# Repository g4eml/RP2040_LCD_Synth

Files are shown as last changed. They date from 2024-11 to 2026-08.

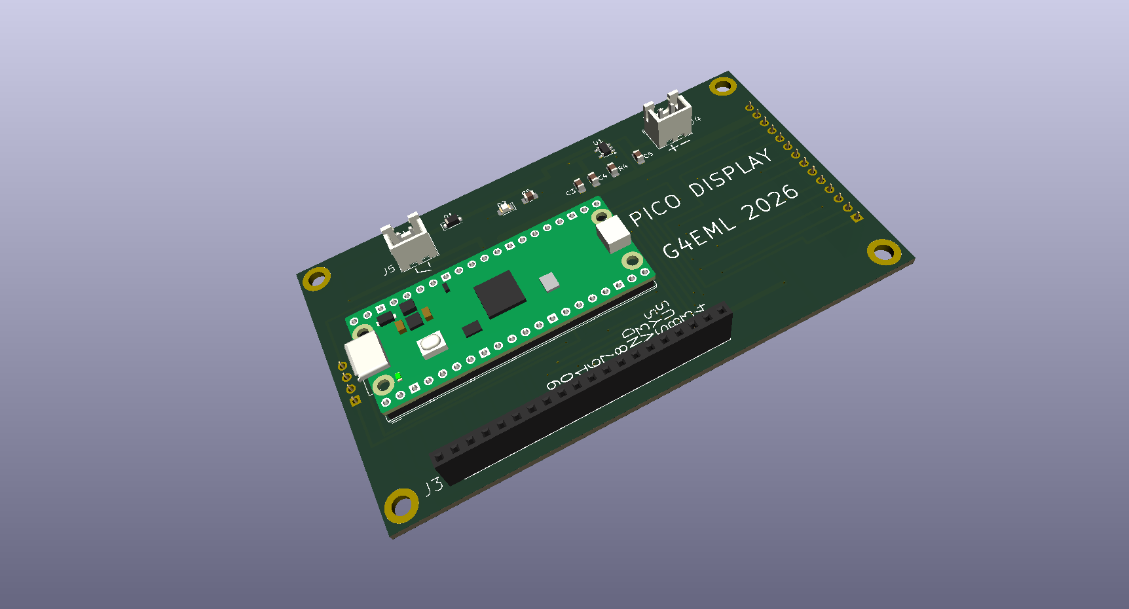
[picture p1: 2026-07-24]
PCB/Pico_Display_Image.png

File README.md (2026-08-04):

# RP2040_LCD_Synth

## Description

This Project is a development of the RP2040_Synth project with the addition of a Touch screen LCD display module, refered to here as the HMI Module (Human Machine Interface). This is intended to be used as a piece of test equipment. 
Currently supports 4 different type of synthesiser chip, the ADF4351, the Max2870, the LMX2595 and the ADF5355.

## Features

Control and configuration can be done from the Touch Screen or from a USB serial port connection. 

No special programming hardware or software required. 

Serial programming using the RP2040s built in USB serial port and standard boot loader. 

Settings are saved to EEPROM for automatic load on power on.

Support for FSK CW Identification for beacon use.

Supports data modes for Beacon Identification.  JT4G is available on all chip types. Q65 is only available on the LMX2595 and ADF5355.

Note:- Whilst JT4G mode is available on all chips there may be some limitations. The ADF4351 and MAX2870 chips have a limited frequency resolution and may not be able to accurately set the required tone frequencies especially when an external multiplication chain is used.

Supports GPS connection for the accurate timing required for data modes. 

Supports 10 different channels which can also be selected by external switches. 

Supports External Key Input with independently configurable FSK Shift. 

Default register settings can be loaded for all synthesiser types to produce some initial RF output. This is often the hardest thing to do with a new chip type.

Supports use with an external frequency multiplier for the higher microwave bands. Allows frequency entry and display of the final output frequency. Adjusts FSK shifts to compensate for multiplication factor.  

Direct output frequency and phase detector frequency entry. Register values are calculated automatically.  

## Requirements

This code was designed to work with the Elecrow CrowPanel Pico-3.5 inch 480x320 TFT LCD HMI Module. https://www.aliexpress.com/item/1005007250778536.html 

LCD_Main

Note:- similar HMI Panels are available using the ESP32 processor chip. Make sure that you are purchasing the RP2040 version. 

## Alternative Display

The correct module now appears to be difficult to obtain. A new interface board has been designed to allow a Raspberry Pi Pico to be fitted to a more easily available 3.5" TFT touch panel. Full Details can be found in the PCB folder. 

Display

Pico_Display_Image

The LCD screen, controller chip and Touch Screen controller appear to be exactly the same as the original module.
 
If you are searching for these online the critical points are that it needs to be a 3.5" display  320 x 480 resolution with an ILI9488 controller and touch screen. 
There are lots of similar displays out there but the correct ones are usually Red and have 14 connections at one end of the board and 4 connections at the other. Be careful as these are also available without the touch screen. 
Full schematic and PCB designs are in the PCB folder. 

## Synthesisers

Suitable Synthesiser boards are available from Ebay, Amazon, Ali Express, SV1AFN etc. 

ADF4351  max2870

lmx2595 SV1AFN

If you wish to use the data modes you will also need a GPS module to provide the necessary accurate timing.  

GPS

## Connecting

All of the various synthesiser moduels use different connectors and pinouts.

The simplest solution is to make an adaptor cable that plugs into the GP connector of the HMI module and fit suitable plugs for the modules to the other end. Keep the wiring as short as possible. Probably no more than 100mm long. 

The power can be provided by the USB-C connector marked 'USB' on the end of the HMI module

## Programming or updating the HMI Module (quick method)

This can be done either before or after the Syntesiser has been connected, it makes no difference. Updating to a new firmware version is done the same way.   

1. Locate the latest compiled firmware file 'RP2040_LCD_Synth.uf2' which will be found here https://github.com/g4eml/RP2040_LCD_Synth/releases and save it to your desktop. 

2. Connect the HMI Module to your PC using the USB-C port on the side. 

3. Hold down the BOOT button on the back of the HMI module and briefly press the Reset button. The RP2040 should appear as a USB disk drive on your PC.

3. Copy the .uf2 file onto the USB drive. The RP2040 will recognise the file and immediately update its firmware and reboot.

## Building your own version of the firmware (longer method and not normally required)

The RP2040 is programmed using the Arduino IDE with the Earl F. Philhower, III  RP2040 core. 

#### Installing the Arduino IDE

1. Download and Install the Arduino IDE 2.3.0 from here https://www.arduino.cc/en/software

2. Open the Arduino IDE and go to File/Preferences.

3. in the dialog enter the following URL in the 'Additional Boards Manager URLs' field: https://github.com/earlephilhower/arduino-pico/releases/download/global/package_rp2040_index.json

4. Hit OK to close the Dialog.

5. Go to Tools->Board->Board Manager in the IDE.

6. Type “RP2040” in the search box.

7. Locate the entry for 'Raspberry Pi Pico/RP2040 by Earle F. Philhower, III' and click 'Install'

### Installing the required libraries

1. From the Arduino IDE select (Tools > Manage Libraries)
2. Search for 'JTEncode' Scroll down to find the Etherkit JTEncode library by Jason Milldrum.
3. Click Install
4. Now search for 'TFT_eSPI' and find the TFT graphics library by Bodmer.
5. Click Install

#### Downloading the Software.

1. Download the latest released source code .zip file from https://github.com/g4eml/RP2040_LCD_Synth/releases

2. Save it to a convenient location and then unzip it.

The TFT_eSPI Library is unusual in that it needs to be configured to the TFT display in use by modifying library files. The required modified versions of the files are located in the 'LCD-eSPI Settings' folder of this repository. Copy the files 'Setup_Elecraft_HMI.h' and 'User_Setup_Select.h' from the downloaded 'LCD-eSPI Settings' folder to your Arduino libraries directory. This will normaly be found at 'Documents/Arduino/libraries/TFT_eSPI'

#### Programming the RP2040

1. Open the Arduino IDE and click File/Open

2. Navigate to the File RP2404Synth/RP2040_LCD_Synth.ino (downloaded in the previous step) and click Open.

3. Select Tools and make the following settings.

   Board: "Raspberry Pi Pico"
   
   Debug Level: "None"

   Debug Port: "Disabled"

   C++ Exceptions: "Disabled"

   Flash Size: "2Mb (no FS)"

   CPU Speed: "133MHz"

   IP/Bluetooth Stack: "IPV4 Only"

   Optimise: "Small (-Os)(standard)"

   RTTI: "Disabled"

   Stack Protection: "Disabled"

   Upload Method: "Default (UF2)"

   USB Stack: "Pico SDK"  

5. Connect the HMI Module to the USB port, hold down the BOOT button and briefly press the reset Button. 

6. Click Sketch/Upload.

The Sketch should compile and upload automatically to the Pico. If the upload fails you may need to disconnect the module and then hold down the BOOT button while reconnecting. 

## Connections

The pinout of the various Synthesiser modules tends to vary so it is difficult to give exact wiring diagrams.
The LMX2595 takes a lot of current so is best supplied from the USB 5V line using its own 3V3 regulator. The other chips can be powered from the 3V3 output of the HMI module. Power arrangements may need additional attention to minimise phase noise. 
The HMI module does not have a connector for the USB 5V supply. You may need to add your own additional wire for this. 

The generic wiring instructions are as follows:-

| HMI Module | ADF4351 | MAX2870 | LMX2595 | ADF5355 |
| :---:  |  :---:  |  :---:  | :---: |  :---:  |
|5V | N/C | N/C | 5V | 5V |
|3V3 | 3V3 | 3V3 | N/C |  N/C |
|GND | GND | GND | GND |  GND |
|GPO3 | CE | CE | CE | CE |
|GPO4 | MUX | MUX |  MUXout |  MUX |
|GPO5 | LE | LE | CSB |  LE |
|GPO6 | CLK | CLK | SCK |  CLK  |
|GPO7 | DAT | DATA  | SDI |  DAT  |

The firmware also supports the optional connection of a GPS module. This is used to accurately set the time, which is needed for the data modes. It is not needed for Local Oscillator or a CW only beacon. Any GPS module with a 3V3 output can be used. It needs to output NMEA data at 9600 Baud. One of the low cost NEO6M modules was used for development. 

| HMI Module | GPS Module |
| :---:  | :---: |
|GP0 |Rx |
|GP1 |Tx |

4 switches can be used to select the operating channel. (These are optional. If they are not used the power-up channel can be selected using the menu.)
The 4 inputs have internal pull up resistors to 3.3V. All that is needed is 4 switches to connect the pins to ground. 
Inverted logic is used. A grounded pin is read as a Logic 1. A floating pin is read as a logic 0.
For example, all pins left open circuit is read as channel 0. 

An external Morse Key can be connected between GP27 and Ground. This can be configured for FSK keying using the K Menu Option. 

| HMI Module | Function |
| :---:  | :---: |
|GP19 |Bit 0  Channel 1|
|GP20 |Bit 1  Channel 2|
|GP21 |Bit 2  Channel 4|
|GP26 |Bit 3  Channel 8|
|GP27 |External Key|

## Firmware description

On first use the screen will show the Touch calibration screen. Follow the instructions and touch each of the four corners of the screen. 

By default on power up the firmware will immediately send the EEPROM saved register values to the sunthesiser chip.  If the CW ident feature is enabled the ident will begin. If the Data mode is enabled the Data sequence will begin. Note that this will initially not be correctly timed. Once the GPS aquires its satellites the timing will synchronise. 

## Main Screen

LCD_Main

The main screen allows entry of output frequency, power setting and output On/Off. 

To change a value just click on the black box and a pop-up alphabetic or numeric keypad will appear. 

10 separate channels (memories) can be selected. 

The power setting is the value sent to the Synthesiser chip, the available range of values will be chip dependent. See the relevant datasheets for more details. 

Entry to the configuration screen is by the Config button. 

The Save button will save the current settings to the selected Channel. 

## Configuring directly from the LCD Screen config page. 

LCD_CONFIG

Configuration should be straightforward. First select the Synthesiser type, then enter the Reference Oscillator Frequency and PFD.  CW Ident and /or JT Mode can be configured if required. 
When complete select Exit to return to the main screen. Then on the main screen select Save to save the new settings to EEPROM. 

## Using the USB serial port and a terminal program such as Putty or Terraterm. Pressing any key should result in the menu being displayed.

Screenshot (112)

### Commands
Commands are entered by a single key press. Text and numbers require a carriage return to enter. Pressing Question Mark will usually give more detailed help. 
Changes to registers and parameters will be applied immediatey so you should be able to observe the result of the change in real time. 

#### The first three Menu Items are common to all channels. 

T = Select Chip Type. Allows the Synthesiser chip type to be selected. Normally only needed the first time you configure the firmware. This will also clear all memories and reset them to the default settings. 

O = Set Reference Oscillator Frequency. Sets the Reference Oscillator Frequency. Enter the actual frequency of your reference including any frequency error. The firmware will attempt to adjust for this. 

N = Set Channel Number. Enter the channel number from 0 to 9. This channel will then be loaded and you can adjust the settings using the menu. This overrides the channel selected by any external switches. if you wish to use external switches to select a channel then you must change this setting to 255 before saving the EEPROM. A setting of 255 enables external channel selection. 

#### The following menu settings are applied to the currently selected channel. Each channel may have different settings. 

D = Restores the Default Register Values for chip. Sets default values to all registers. Tries to program a 10Mhz PFD and requests a frequency. After this your Synthesiser should start to output RF. 

P = Enter PFD Frequency. Set the required PFD frequency. The firmware will attempt to get as close as possible to the requested value but not all values can be achieved.

M = Set External Multiplier. If the Synthesiser is followed by a multiplier for higher frequencies this option allows you to specify the multiplcation factor. Final Multiplied Frequencies can then be entered and viewed. 

F = Enter Output Frequency. Set the required output frequency. The firmware will attempt to calculate the closest register values to achieve this. Changing the PFD may improve the result. 

C = Calculate and display frequency from current settings. The firmware will calculte the expected output frequency from the current register settings. Useful to check after youy make manual changes.

V = View / Enter Variables for Registers. Allows viewing or entry of parameters using the same names as defined in the chip datasheet. Press ? for a full list of the available parameter names. 

R = View / Enter Registers Directly in Hex. Allws direct entry of regiser values in Hexadecimal. Useful when transfering values calculated by another program. 

I = Configure CW Ident. Alows entry of CW Ident, CW Speed, Ident Period and FSK Shift.  A shift of -800Hz is a typical value. Ident period is only valid for a CW only configuration. If a JT mode is also enbled then the CW ident will be sent every odd minute. 

J = Configure data modes. Allows entry of a 13 character message for JT4G. This would normally be the Callsign and Maidenhead locator. For Q65 this must be the callsign and 4 character locator. The ident will be sent every Even minute. Accurate timing requires a GPS module to be connected.

K = Configure External Key. An External Morse key can be connected and used to frequency shift the signal. The FSK Shift can be entered and is seperate from the CWID shift. 

G = View GPS NMEA data. This is used to test the GPS connection. when selected it will echo all GPS data to the screen. Press any key to exit this mode. 

S = Save Registers to EEPROM. Saves the current Synthesiser settings to EEPROM. They will then be automatically loaded on the next power cycle. You must do this at least once. 

X = Exit Menu. Exits from the menu, re-initialises the Synthesiser and starts the CW Ident. 

##

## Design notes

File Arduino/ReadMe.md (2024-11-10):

# This Folder contains the Arduino Sketch

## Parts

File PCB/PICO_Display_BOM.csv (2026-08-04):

Id | Designator | Footprint | Quantity | Designation | Supplier and ref
1 | A1 | RaspberryPi_Pico_Common_THT | 1 | RaspberryPi_Pico
2 | C3 | C_0805_2012Metric_Pad1.18x1.45mm_HandSolder | 1 | 100nF
3 | C4, C5 | C_0805_2012Metric_Pad1.18x1.45mm_HandSolder | 2 | 22uF
4 | D1 | D_SOD-123F | 1 | D_Schottky
5 | D2 | LED_0805_2012Metric_Pad1.15x1.40mm_HandSolder | 1 | LED
6 | J1 | PinSocket_1x14_P2.54mm_Vertical | 1 | Conn_01x14_Socket
7 | J2 | PinSocket_1x04_P2.54mm_Vertical | 1 | Conn_01x04_Socket
8 | J3 | PinSocket_1x20_P2.54mm_Vertical | 1 | Conn_01x18_Socket
9 | J4, J5 | JST_XH_B2B-XH-A_1x02_P2.50mm_Vertical | 2 | Conn_01x02_Pin
10 | R4 | C_0805_2012Metric_Pad1.18x1.45mm_HandSolder | 1 | 2K
11 | R5 | C_0805_2012Metric_Pad1.18x1.45mm_HandSolder | 1 | 4K7
12 | U1 | TSOT-23-5 | 1 | LTC4054ES5-4.2

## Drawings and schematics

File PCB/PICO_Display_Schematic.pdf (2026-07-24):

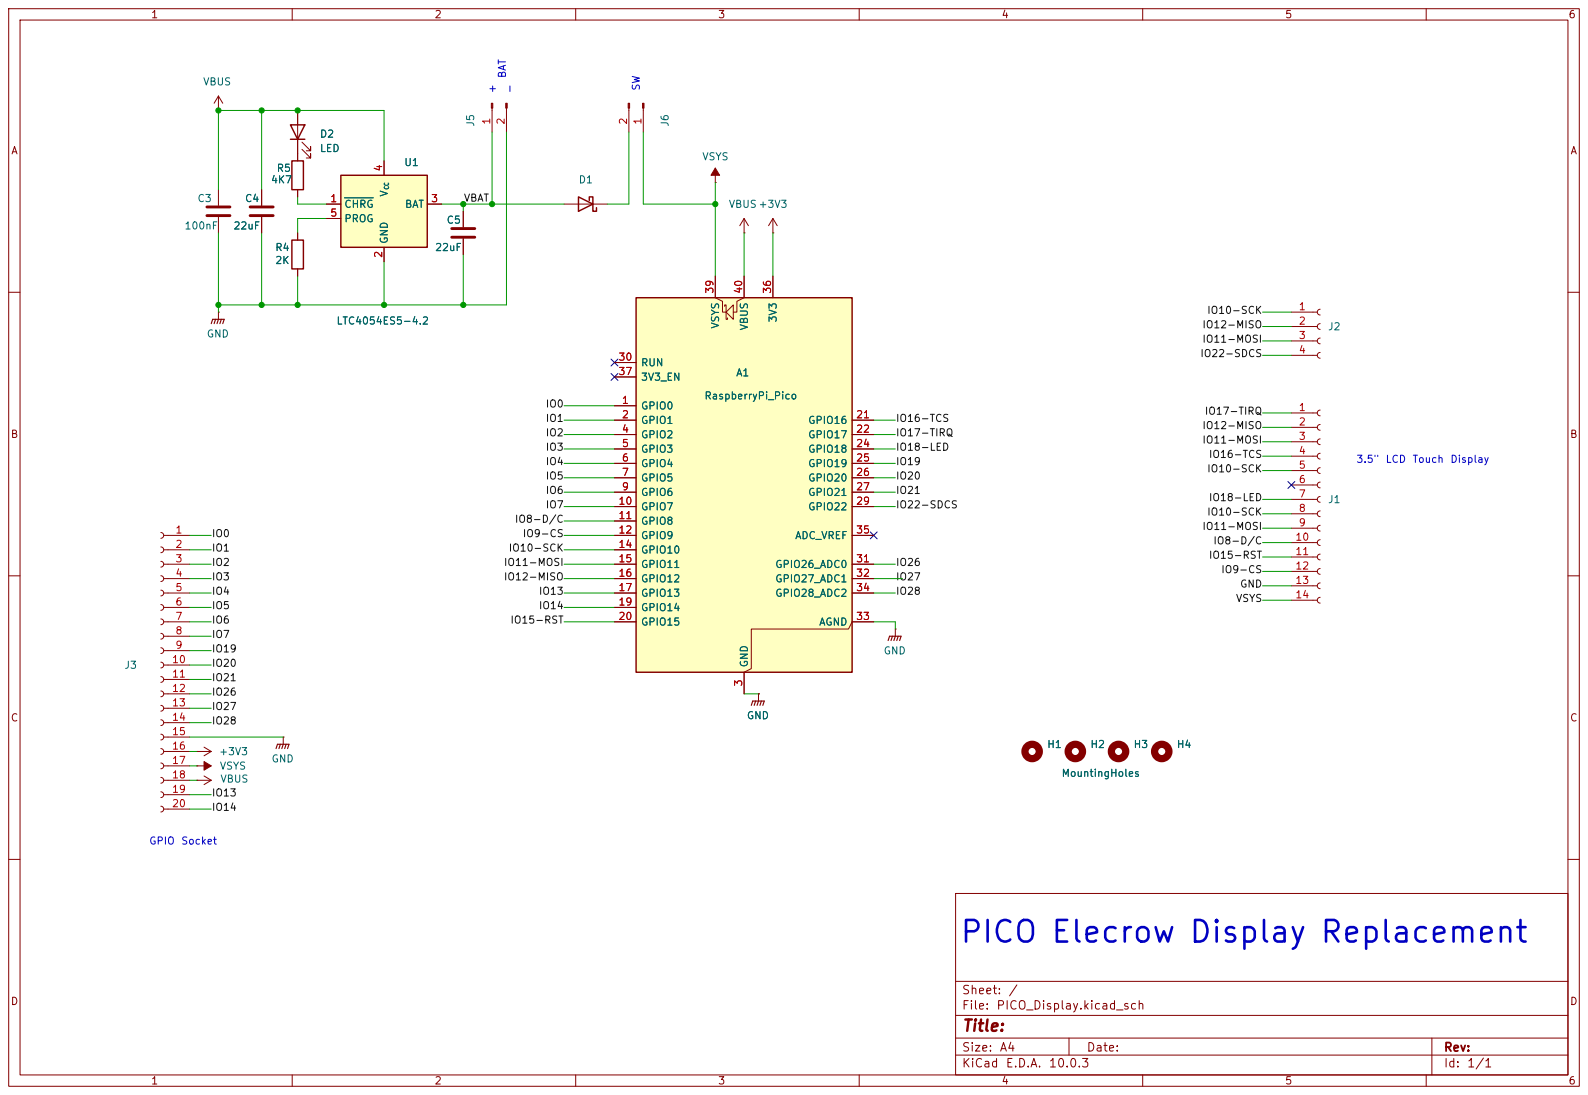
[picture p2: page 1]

PICO Elecrow Display Replacement

Size: A4 | Rev:
KiCad E.D.A. 10.0.3 | Id: 1/1

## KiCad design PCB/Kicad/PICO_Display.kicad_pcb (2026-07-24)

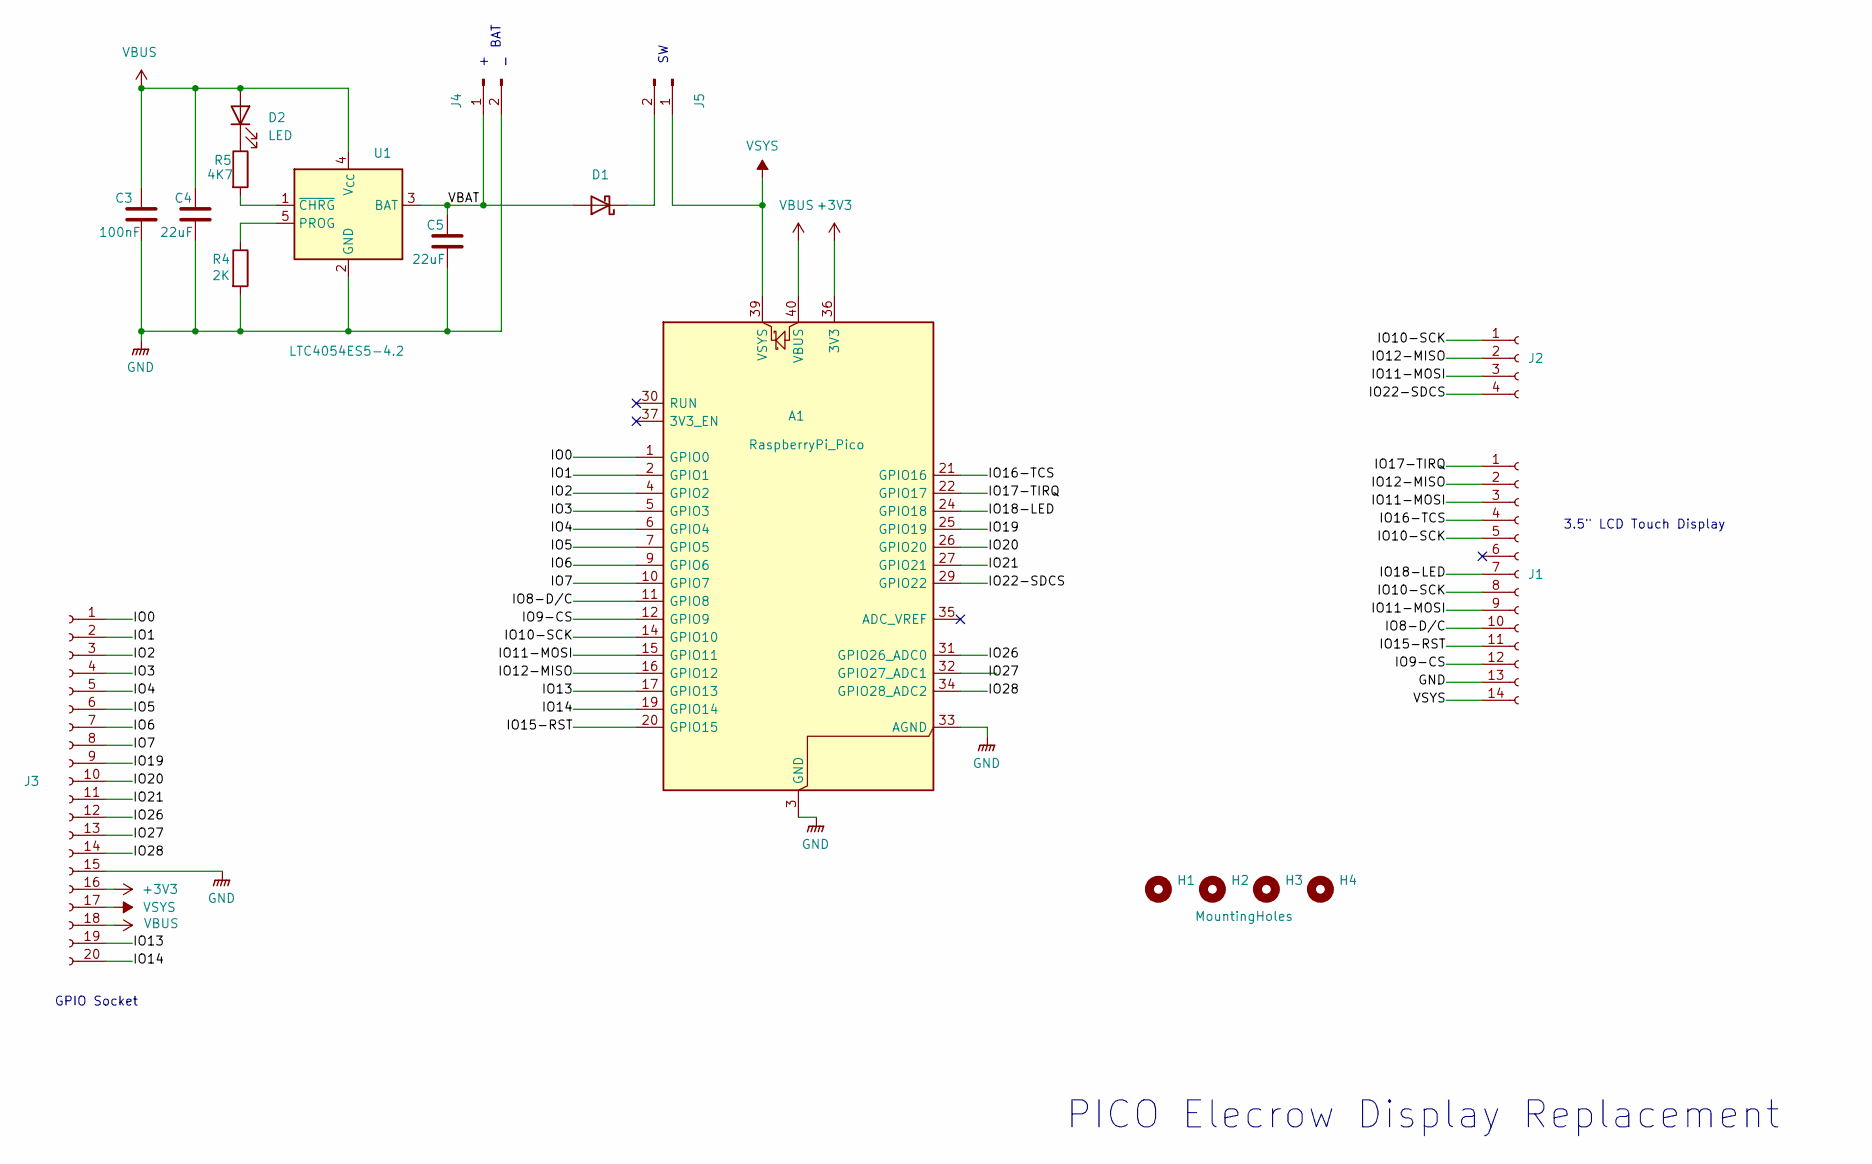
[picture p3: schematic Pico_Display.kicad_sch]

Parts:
A1: RaspberryPi_Pico; RaspberryPi_Pico_Common_THT
C3: 100nF; C_0805_2012Metric_Pad1.18x1.45mm_HandSolder
C4, C5: 22uF; C_0805_2012Metric_Pad1.18x1.45mm_HandSolder
D1: D_Schottky; D_SOD-123F
D2: LED; LED_0805_2012Metric_Pad1.15x1.40mm_HandSolder
H1, H2, H3: MountingHole; MountingHole_3.2mm_M3_ISO14580_Pad
H4: MountingHoles; MountingHole_3.2mm_M3_ISO14580_Pad
J1: Conn_01x14_Socket; PinSocket_1x14_P2.54mm_Vertical
J2: Conn_01x04_Socket; PinSocket_1x04_P2.54mm_Vertical
J3: Conn_01x18_Socket; PinSocket_1x20_P2.54mm_Vertical
J4, J5: Conn_01x02_Pin; JST_XH_B2B-XH-A_1x02_P2.50mm_Vertical
R4: 2K; C_0805_2012Metric_Pad1.18x1.45mm_HandSolder
R5: 4K7; C_0805_2012Metric_Pad1.18x1.45mm_HandSolder
U1: LTC4054ES5-4.2; TSOT-23-5

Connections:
+3V3: A1.36 (3V3), J3.16
/IO0: A1.1 (GPIO0), J3.1
/IO1: A1.2 (GPIO1), J3.2
/IO2: A1.4 (GPIO2), J3.3
/IO3: A1.5 (GPIO3), J3.4
/IO4: A1.6 (GPIO4), J3.5
/IO5: A1.7 (GPIO5), J3.6
/IO6: A1.9 (GPIO6), J3.7
/IO7: A1.10 (GPIO7), J3.8
/IO8-D/C: A1.11 (GPIO8), J1.10
/IO9-CS: A1.12 (GPIO9), J1.12
/IO10-SCK: A1.14 (GPIO10), J1.5, J1.8, J2.1
/IO11-MOSI: A1.15 (GPIO11), J1.3, J1.9, J2.3
/IO12-MISO: A1.16 (GPIO12), J1.2, J2.2
/IO13: A1.17 (GPIO13), J3.19
/IO14: A1.19 (GPIO14), J3.20
/IO15-RST: A1.20 (GPIO15), J1.11
/IO16-TCS: A1.21 (GPIO16), J1.4
/IO17-TIRQ: A1.22 (GPIO17), J1.1
/IO18-LED: A1.24 (GPIO18), J1.7
/IO19: A1.25 (GPIO19), J3.9
/IO20: A1.26 (GPIO20), J3.10
/IO21: A1.27 (GPIO21), J3.11
/IO22-SDCS: A1.29 (GPIO22), J2.4
/IO26: A1.31 (GPIO26_ADC0), J3.12
/IO27: A1.32 (GPIO27_ADC1), J3.13
/IO28: A1.34 (GPIO28_ADC2), J3.14
/VBAT: C5.2, D1.2 (A), J4.1, U1.3 (BAT)
GND: A1.3 (GND), A1.8 (GND), A1.13 (GND), A1.18 (GND), A1.23 (GND), A1.28 (GND), A1.33 (AGND), A1.38 (GND), C3.1, C4.1, C5.1, J1.13, J3.15, J4.2, R4.2, U1.2 (GND)
unnamed: D1.1 (K), J5.2
unnamed: D2.1 (K), R5.1
unnamed: R4.1, U1.5 (PROG)
unnamed: R5.2, U1.1 (~CHRG)
VBUS: A1.40 (VBUS), C3.2, C4.2, D2.2 (A), J3.18, U1.4 (V_{CC})
VSYS: A1.39 (VSYS), J1.14, J3.17, J5.1

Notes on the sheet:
PICO Elecrow Display Replacement
BAT
3.5" LCD Touch Display
GPIO Socket

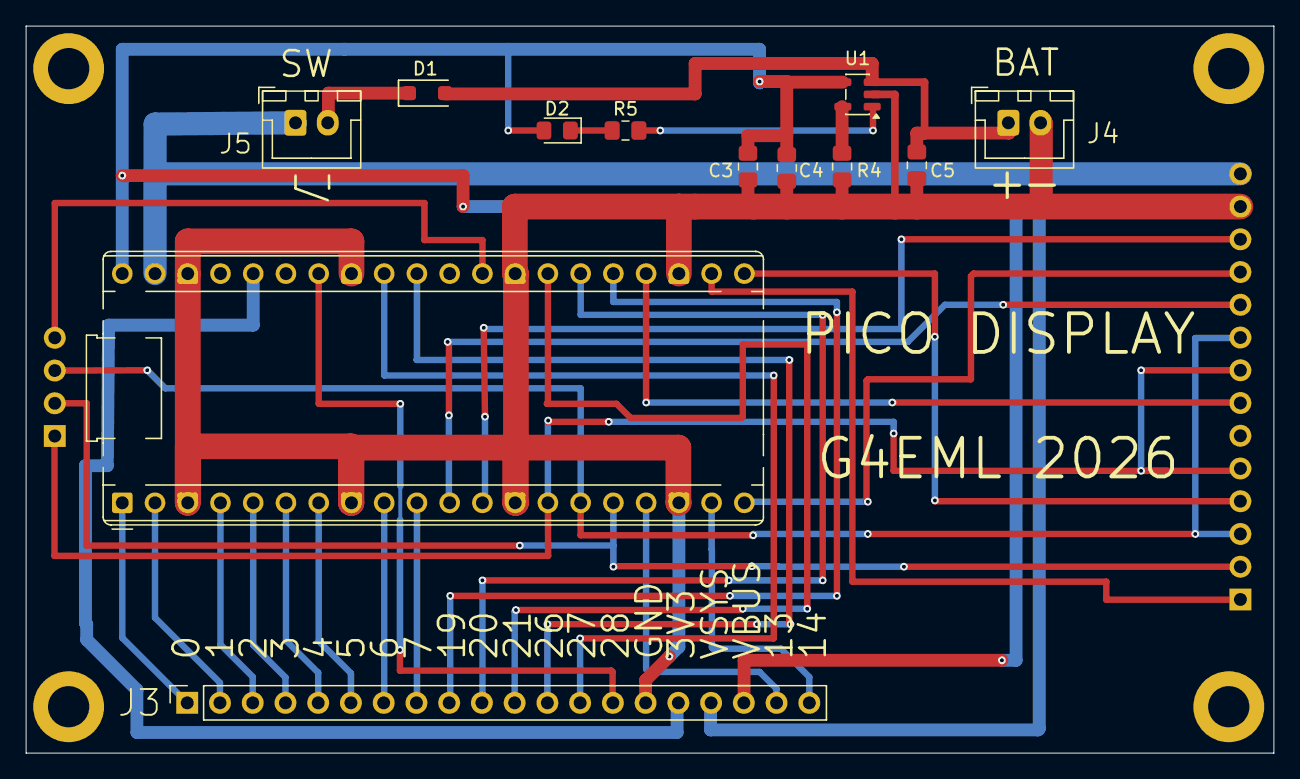
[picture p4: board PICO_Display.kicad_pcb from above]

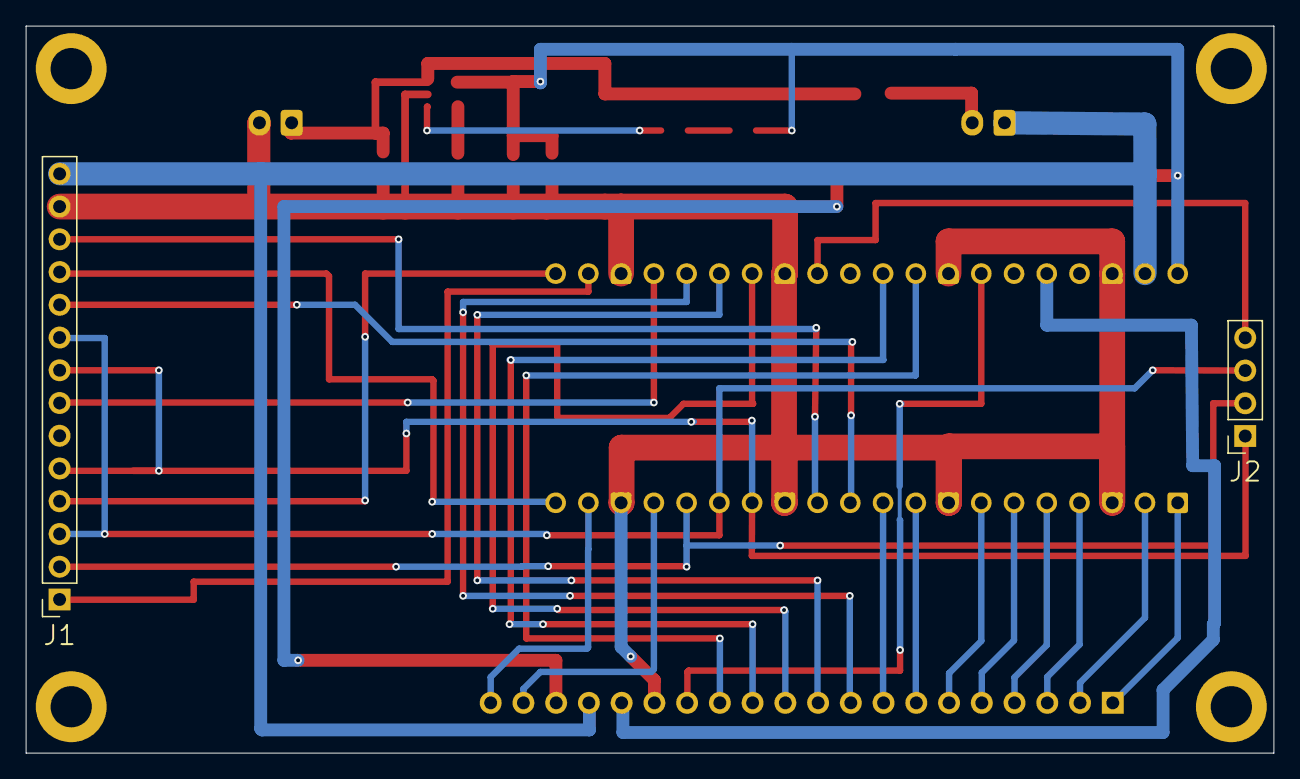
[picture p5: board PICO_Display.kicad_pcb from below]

Board: 2 copper layers, 96.8 x 56.4 mm, 18 parts (2 on the bottom side), 35 nets.

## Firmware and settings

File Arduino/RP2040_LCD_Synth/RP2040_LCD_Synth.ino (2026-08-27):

// Synthesiser controller with touchscreen LCD interface
// Colin Durbridge G4EML 2024
// Optional support for LCD controller using crowpanel 3.5" HMI panel.

#include "SynthChip.h"
#include "ChipList.h"

#define LCDVERSION

#define VERSION 2.00

#define EEPROMVER 0x53

#define NUMBEROFCHANNELS 10

//Global values...

//enum chipType and NUM_CHIP_TYPES are both generated from CHIP_LIST in ChipList.h -
//to add a new chip type, edit that list, not this one.
enum chipType
{
  NONE,
  #define CHIP_ENTRY(name, instance) name,
  CHIP_LIST
  #undef CHIP_ENTRY
  NUM_CHIP_TYPES        //always 1 past the last valid chip type; also equals the number of chip types including NONE
};

//Each chip's display name is set in its own constructor (see e.g. MAX2870.ino) and
//retrieved via chipTypeName(index) in redirects.ino - there is no separate name list to update.

//Pointer to the SynthChip object for the currently selected chip type.
//Set (and kept in sync with "chip") by chipInit() in redirects.ino.
//To add a new chip type see the notes at the top of SynthChip.h.
SynthChip* activeChip = nullptr;

bool saveRequired = false;

//These values are saved to the eeprom for recall on statup. 
//these values alpply to all channels

uint8_t chip = MAX2870;                 //index to the current chip type (applies to all channels)
uint8_t selChan = 0;                    //FF if channel is externally selected by switches. Channel number to force one channel. 
double refOsc = 100.000 ;               //reference oscillator frequency in MHz (applies to all channels)
uint16_t batcal = 492;                  //battery calibration value

//Bit definitions for fskMode flags

#define CWIDBIT 0x01
#define NOTCWIDBIT 0xFE
#define EXTKEYBIT 0x02
#define NOTEXTKEYBIT 0xFD

//this structure is repeated for each channel

struct chanstruct
{
uint32_t reg[80];                       // allow for up to 80 32 bit registers. 
uint8_t fskMode = 0;                    // 8 flag bits to indicate enabled special FSK modes.  Bit 0 = CWID   Bit 1 = External Key  
uint8_t cwidLen = 1;                    //number of characters in the CWID
uint8_t cwidSpeed = 10;                 //CWID speed in words per minute
uint8_t cwidInterval = 60;              //CWID Inteval in seconds.
float cwidShift = 0;                    //CW ID FSK Shift in MHz 
float keyShift = 0;                     //external key FSK Shift in MHz 
char cwid[32] = " ";                    // up to 30 CWID characters
uint8_t jtMode = 0;                     //JT mode
char jtid[13] = " ";                    //JT Message
float jtTone1 = 0;                      //JT Tone 1 Offset from Nominal Frequency (Mhz)
uint8_t jtInterval = 60;              //Digi mode Interval in seconds.
uint8_t extMult = 1;                    //Multiplcation factor for external frequency multiplier. (used to calculate the correct FSK Shifts.)
};

struct chanstruct chanData[NUMBEROFCHANNELS];


//End of saved values

//Note: numberOfRegs, maxPfd, minPfd, maxOsc, minOsc, jt4Only and jtDisable used to be
//duplicated here as globals, kept in sync with the selected chip by chipInit(). They are
//now read directly from activeChip (e.g. activeChip->numberOfRegs) wherever needed, so
//there is only one copy of this data - the one on the chip object itself.
uint8_t channel = 0;                      //currently active channel.

uint32_t cwidKeyUpN = 1;                  //key up value for the PLL N used to shift the frequency for CWID. Calculated by cwidInit()
uint32_t cwidKeyUpNum = 1;                //Key up value for the PLL numerator used to shift the frequency for CWID. Calculated by cwidInit()
uint32_t cwidKeyUpDen = 1;                //Key up value for the PLL denominator used to shift the frequency for CWID. Calculated by cwidInit()

uint32_t ExtKeyUpN = 1;                  //key up value for the PLL N used to shift the frequency for External Key. Calculated by ExtKeyInit()
uint32_t ExtKeyUpNum = 1;                //Key up value for the PLL numerator used to shift the frequency for External Key. Calculated by ExtKeyInit()
uint32_t ExtKeyUpDen = 1;                //Key up value for the PLL denominator used to shift the frequency for External Key. Calculated by ExtKeyInit()

void saveSettings(void);

#include <EEPROM.h>
#include <SPI.h>
#include <JTEncode.h>



#define JT4G_TONE_SPACING        315         // 72 * 4.37 Hz
#define JT4_DELAY                229         // Delay value for JT4
#define Q65_TONE_SPACING        3.33333       // 3.3333 Hz for Mode 30A
#define Q65_DELAY               150         // Delay in ms for Q65 15
#define Q65_SYMBOL_COUNT     85          //85 symbols


uint8_t jtBuffer[256];
uint8_t jtSymbolCount;
uint16_t jtToneDelay;
double jtToneSpacing;
uint8_t jtNumberOfTones;

uint32_t jtN[66];               //Note Element 0 is the nominal frequency. Element 1 is the Tone 1 frequency
uint32_t jtNum[66];
uint32_t jtDen[66];


JTEncode jtEncode;

int seconds = 0;                         //seconds counter.  counts up to 120 seconds.  0-60 is even minute. 60-120 is odd minute. 
int milliseconds = 0;                   //millisecond counter used to increment seconds counter. 

bool cwidActive = false;                //flag to start sending CW ID
int nextcwidTime = 60;                   //trigger time for next CWID

bool jtActive = false;                  //flag to start Jt Sending
int  nextjtTime = 1;                       //trigger time for next JT sequence

bool lastKeyState = 1;                 //external key state last pass 1 = key up 0 = key down

#define GPSTXPin 0                      //Serial data to GPS module 
#define GPSRXPin 1                      //SeriaL data from GPS module

//The touchscreen board's TFT_eSPI wiring uses GPIO 10-14, so channel select and
//external key use different pins here than on the non-LCD board.
#define CHANSEL0Pin 19                  //External channel select pins. Pulled up to 3V3. High is Logic 0 Low is Logic 1
#define CHANSEL1Pin 20
#define CHANSEL2Pin 21
#define CHANSEL3Pin 26
#define EXTKEYPin 27                    //External Key input Pulled upp to 3V3 ground to key

char gpsBuffer[256];                     //GPS data buffer
int gpsPointer;                          //GPS buffer pointer. 
char gpsCh;
int gpsSec = -1;                         //gps Seconds counter 0-59 is even minute, 60-119 is odd minute. -1 is GPS Invalid 
bool gpsActive = false; 
int lastsec=0;
int gpsH=0;
int gpsM=0;
int gpsS=0;

bool showSync=false;
bool showingGPS = false;
int gpstimeout =0;

#include <TFT_eSPI.h>      // Hardware-specific library. Must be pre-configured for this display and touchscreen
TFT_eSPI tft = TFT_eSPI(); // Invoke custom library
// Set REPEAT_CAL to true instead of false to run calibration again, otherwise it will only be done once.
#define REPEAT_CAL false
uint16_t t_x = 0, t_y = 0; // To store the touch coordinates

//Set true by a screen/pad right before it returns after acting on a touch (e.g.
//selecting an item from a popup list). While true, getTouchDebounced() reports
//"not touched" regardless of what the touch controller says, so the same
//physical touch can't immediately bleed through and re-trigger something on the
//screen underneath as soon as it redraws. Cleared automatically the first time
//a genuine release is seen. See getTouchDebounced() in commonScreen.ino.
bool touchConsumed = false;

void setup() 
{
  Serial.begin();                       //USB serial port
  analogReadResolution(12);
  Serial1.setRX(GPSRXPin);              //Configure the GPIO pins for the GPS module
  Serial1.setTX(GPSTXPin);

  pinMode(CHANSEL0Pin, INPUT_PULLUP);   //configure the channel select pins. 
  pinMode(CHANSEL1Pin, INPUT_PULLUP);   //Inverted logic to allow switches to ground. 
  pinMode(CHANSEL2Pin, INPUT_PULLUP);
  pinMode(CHANSEL3Pin, INPUT_PULLUP);

  pinMode(EXTKEYPin, INPUT_PULLUP);     //configure the external Key Input

  Serial1.begin(9600);                  //start GPS port comms on pins 0 and 1
  gpsPointer = 0;
  delay(1000);
  EEPROM.begin(4096);
  if(EEPROM.read(0) == EEPROMVER)        //magic number to indcate EEPROM is valid
    {
      EEPROM.get(1,chip);              //chip type for all channels
      EEPROM.get(2,selChan);           //read the selected channel. 0xFF if externally switched.
      EEPROM.get(3,refOsc);           //reference oscillator for all channels.
      EEPROM.get(11,batcal);          //battery cal factor 
      EEPROM.get(13,chanData);         //get channel data structure.
      if(selChan == 255)
        {
          channel = readChannelInputs();      //read the channel select bits. 
        }
      else
        {
          channel = selChan;          //fix the channel number. 
        } 
    }
  else
    {
      changeChip();                 //blank/invalid EEPROM - force reset of all channels to valid defaults.
    }
   chipInit();
   initChannel();
   seconds = -1;

  tft.init();
  tft.setRotation(1);
  if(homeScreenTouched())
   {
    while(homeScreenTouched());
    delay(1000);
    touch_calibrate(1);
   }
   else
   {
    touch_calibrate(0);
   }
  homeScreenUpdate();

}

void loop() 
{
  Serial.print("\n");
  Serial.print(chipTypeName(chip));
  Serial.println(" Synthesiser programmed, Sleeping");

  chipUpdate();
  delay(100);
  chipUpdate();
  
  unsigned long loopTimer = millis();
  while(1)
   {
     while(loopTimer == millis());          //hang waiting for the next 1mS timeslot
     loopTimer = millis();
     milliseconds++;
     if(milliseconds == 1000)
      {
        seconds++;
        milliseconds = 0;
        if(seconds == 120)
          {
            seconds = 0;
          }
        displayVolts();
      }

     if((gpsSec !=-1)&&(gpsS != lastsec))
       {
        lastsec=gpsS;
        displayGPS();
        showingGPS = true;
        gpstimeout = 0;
        if(gpsSec != seconds) 
         {
          seconds = gpsSec;
          milliseconds = 500;
         }      
       }

    if(showingGPS)
    {
      gpstimeout++;
    }

    if((gpstimeout > 10000) && (showingGPS))
      {
        showingGPS = false;
        gpsSec = -1;
        homeScreenUpdate();
      }

//synchronise the local clock to the GPS clock if available

     if(selChan == 255)             //external chaannel selection
       {
         uint8_t newChan=readChannelInputs();
         if(newChan != channel)
           {
            channel=newChan;
            seconds = -1;                       //reset the timing after changing channel.
            milliseconds = 0;
            jtActive = false;
            cwidActive = false;
            chipUpdate();
            initChannel();
           }

       }

     if((chanData[channel].fskMode & CWIDBIT) && (seconds == nextcwidTime))
       {
        cwidActive = true;                                        //start this CW ID
        nextcwidTime = (seconds + chanData[channel].cwidInterval) % 120;            //schedule the next CW ID
       }

     if((chanData[channel].jtMode != 0) && (seconds == nextjtTime))
       {
        jtActive = true;                                        //start the JT Sequence
        nextjtTime = (seconds + chanData[channel].jtInterval) % 120;            //schedule the next CW ID
       }

    if(chanData[channel].fskMode & CWIDBIT)
      {
        cwidTick();
      }

    if(chanData[channel].jtMode != 0)
      {
        jtTick();
      }

    if(chanData[channel].fskMode & EXTKEYBIT)
      {
        keyTick();
      }

      if(Serial.available() > 0 )          //test for USB command connected
     {
      bool valid = false;
         while(Serial.available())
         {
           if(Serial.read() == 13)
            {
              valid = true;
            }
         }
       if(!valid) return;
       chipExtKey(true);                    //reset to nominal carrier frequency
       mainMenu();                         //timing loop stops while the menu system is running.
       seconds = -1;                       //reset the timing after using the menu.
       milliseconds = 0;
       initChannel();  
       chipUpdate();    
       Serial.print("\nSynthesiser programmed. Press any key for menu");
       delay(500);
       flushInput();
     }
    
    if(Serial1.available() > 0)           //data received from GPS module on pins 0 and 1
      {
        while(Serial1.available() >0)
          {
            gpsCh=Serial1.read();
            if(gpsCh > 31) gpsBuffer[gpsPointer++] = gpsCh;
            if((gpsCh == 13) || (gpsPointer > 255))
              {
                gpsBuffer[gpsPointer] = 0;
                processNMEA();
                gpsPointer = 0;
              }
          }

      }

   if(homeScreenTouched())
    {
    if(processHomeScreenTouch())
      {
       homeScreenUpdate();
      }
    }   

  }  
}

void initChannel()
{
  chipDecodeRegs();
  if(chanData[channel].fskMode & CWIDBIT)
    {
      cwidInit();
    }
   
  if(chanData[channel].fskMode & EXTKEYBIT)
    {
      keyInit();
    }

   if(chanData[channel].jtMode)
     {
       jtInit();
     }


}

void processNMEA(void)
{
  float gpsTime;

 if(strstr(gpsBuffer , "RMC") != NULL)                         //is this the RMC sentence?
  {
    if(strstr(gpsBuffer , ",A,") != NULL)                       // is the data valid?
      {
       int p=strcspn(gpsBuffer , ",");                         // find the first comma
       gpsTime = strtof(gpsBuffer+p+1 , NULL);                 //copy the time to a floating point number
       gpsSec = 60 * ((int(gpsTime) / 100) % 2);                 // count odd and even minutes
       gpsSec = gpsSec + (int(gpsTime) % 100); 
       gpsH=int(gpsTime)/10000;
       gpsM=(int(gpsTime)/100) % 100;
       gpsS= int(gpsTime) % 100;
       gpsActive = true;
      }
    else
     {
       gpsSec = -1;                                            //GPS time not valid
     }
  }


}

uint8_t readChannelInputs(void)
{
  uint8_t ch;
  ch = (digitalRead(CHANSEL3Pin) << 3) | (digitalRead(CHANSEL2Pin) << 2) | (digitalRead(CHANSEL1Pin) << 1) | (digitalRead(CHANSEL0Pin));
  ch = ~ch & 0x0F;           //invert the logic and limit to 4 bits. 
  if(ch > (NUMBEROFCHANNELS -1)) ch = NUMBEROFCHANNELS-1;
  return ch;
}

void saveSettings(void)
{
    EEPROM.write(0, EEPROMVER);         //magic number to indcate EEPROM is valid
    EEPROM.put(1,chip);            //save the chip type
    EEPROM.put(2,selChan);         //Save the currently selected channel
    EEPROM.put(3,refOsc);          //reference oscillator for all channels.
    EEPROM.put(11,batcal);           //battery calibration factor
    EEPROM.put(13,chanData);         //get channel data structure. 
    EEPROM.commit();
}

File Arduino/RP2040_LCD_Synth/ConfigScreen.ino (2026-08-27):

//Chip type - single field showing the current chip; tap to open the full
//auto-populated selection list (see ChipPad.ino). No positions to add here
//when a new chip type is added.
#define CHIP_LX 10
#define CHIP_LY 15
#define CHIP_X 130
#define CHIP_Y 5
#define CHIP_W 200
#define CHIP_H 20

//Reference Frequency
#define REF_LX 10
#define REF_LY 40
#define REF_X 180
#define REF_Y 30
#define REF_W 110
#define REF_H 20

//PFD
#define PFD_LX 320
#define PFD_LY 40
#define PFD_X 370
#define PFD_Y 30
#define PFD_W 105
#define PFD_H 20

//MULT
#define MULT_LX 10
#define MULT_LY 65
#define MULT_X 180
#define MULT_Y 55
#define MULT_W 40
#define MULT_H 20

//Key Shift
#define KEYSH_LX 10
#define KEYSH_LY 90
#define KEYSH_X 200
#define KEYSH_Y 80
#define KEYSH_W 100
#define KEYSH_H 20

//CWID
#define CWID_LX 10
#define CWID_LY 115
#define CWID_X 100
#define CWID_Y 105
#define CWID_W 375
#define CWID_H 20

//CWSP
#define CWSP_LX 10
#define CWSP_LY 140
#define CWSP_X 170
#define CWSP_Y 130
#define CWSP_W 50
#define CWSP_H 20

//CWINT
#define CWINT_LX 240
#define CWINT_LY 140
#define CWINT_X 405
#define CWINT_Y 130
#define CWINT_W 50
#define CWINT_H 20


//CW Shift
#define CWSH_LX 10
#define CWSH_LY 165
#define CWSH_X 170
#define CWSH_Y 155
#define CWSH_W 100
#define CWSH_H 20

//CW Enable
#define CWEN_LX 300
#define CWEN_LY 165
#define CWEN_X 380
#define CWEN_Y 155
#define CWEN_W 20
#define CWEN_H 20

//JTmode 0
#define JTM0_LX 10
#define JTM0_LY 190
#define JTM0_X 125
#define JTM0_Y 180
#define JTM0_W 20
#define JTM0_H 20

//JTmode JT4
#define JTM1_LX 155
#define JTM1_LY 190
#define JTM1_X 205
#define JTM1_Y 180
#define JTM1_W 20
#define JTM1_H 20

//JTmode Q65
#define JTM2_LX 235
#define JTM2_LY 190
#define JTM2_X 272
#define JTM2_Y 180
#define JTM2_W 20
#define JTM2_H 20

//Q65 Submode
#define Q65M_LX 300
#define Q65M_LY 190
#define Q65M_X 390
#define Q65M_Y 180
#define Q65M_W 50
#define Q65M_H 20


//JTT1
#define JTT1_LX 10
#define JTT1_LY 215
#define JTT1_X 200
#define JTT1_Y 205
#define JTT1_W 100
#define JTT1_H 20

//JTID
#define JTID_LX 10
#define JTID_LY 240
#define JTID_X 90
#define JTID_Y 230
#define JTID_W 200
#define JTID_H 20

//Spare row (new line) - Y=255, LY=265 available for a new field before the Exit button

//Battery Cal
#define BATCAL_LX 10
#define BATCAL_LY 305
#define BATCAL_X 160
#define BATCAL_Y 290
#define BATCAL_W 70
#define BATCAL_H 30

//exit Button

#define EXIT_X 400
#define EXIT_Y 290
#define EXIT_W 70
#define EXIT_H 30


void configScreenUpdate(void) 
{
  char Q65MODE[7][4]={"15A","15B","15C","30A","30B","30C","30D"};
  tft.fillScreen(TFT_CYAN);
  drawLabel(CHIP_LX, CHIP_LY, "Chip Type", TFT_BLUE,0);
  drawTextBox(CHIP_X, CHIP_Y, CHIP_W, CHIP_H, chipTypeName(chip), false, 0);
  drawLabel(REF_LX, REF_LY, "Reference Oscillator", TFT_BLUE,0);
  drawNumBox(REF_X, REF_Y, REF_W, REF_H, refOsc, 6, false);
  drawLabel(PFD_LX, PFD_LY, "PFD", TFT_BLUE,0);
  drawNumBox(PFD_X, PFD_Y, PFD_W, PFD_H, chipGetPfd(), 6, false);
  drawLabel(MULT_LX, MULT_LY, "External Multiplier X", TFT_BLUE,0);
  drawNumBox(MULT_X, MULT_Y, MULT_W, MULT_H, chanData[channel].extMult, 0, false);
  drawLabel(KEYSH_LX, KEYSH_LY, "Ext Key FSK Shift (Hz)", TFT_BLUE,0);
  drawNumBox(KEYSH_X, KEYSH_Y, KEYSH_W, KEYSH_H, (chanData[channel].keyShift * 1000000.0), 0, false);
  drawLabel(CWID_LX, CWID_LY, "CW Ident", TFT_BLUE,0);
  drawTextBox(CWID_X, CWID_Y, CWID_W, CWID_H, &chanData[channel].cwid[1],false,0);
  drawLabel(CWSP_LX, CWSP_LY, "CW Speed (WPM)", TFT_BLUE,0);
  drawNumBox(CWSP_X, CWSP_Y, CWSP_W, CWSP_H, chanData[channel].cwidSpeed, 0, false);
  drawLabel(CWINT_LX, CWINT_LY, "CW Interval (Secs)", TFT_BLUE,0);
  drawNumBox(CWINT_X, CWINT_Y, CWINT_W, CWINT_H, chanData[channel].cwidInterval, 0, false);
  drawLabel(CWSH_LX, CWSH_LY, "CW FSK Shift (Hz)", TFT_BLUE,0);
  drawNumBox(CWSH_X, CWSH_Y, CWSH_W, CWSH_H, (chanData[channel].cwidShift * 1000000.0), 0, false);
  drawLabel(CWEN_LX, CWEN_LY, "CWID On", TFT_BLUE,0);
  drawOnOff(CWEN_X, CWEN_Y, CWEN_W, CWEN_H, chanData[channel].fskMode & CWIDBIT);
  drawLabel(JTID_LX, JTID_LY, "Digi Ident", TFT_BLUE,0);
  drawTextBox(JTID_X, JTID_Y, JTID_W, JTID_H, chanData[channel].jtid,false,0);
  drawLabel(JTT1_LX, JTT1_LY, "Digi Tone 1 Offset (Hz)", TFT_BLUE,0);
  drawNumBox(JTT1_X, JTT1_Y, JTT1_W, JTT1_H, (chanData[channel].jtTone1 * 1000000.0) , 0, false);
  drawLabel(BATCAL_LX, BATCAL_LY, "Battery Calibrate", TFT_BLUE,0);
  drawNumBox(BATCAL_X, BATCAL_Y, BATCAL_W, BATCAL_H, getVolts(0), 2, false);
  if(!activeChip->jtDisable)
    {
    drawLabel(JTM0_LX, JTM0_LY, "Digi Mode Off", TFT_BLUE,0);
    drawOnOff(JTM0_X, JTM0_Y, JTM0_W, JTM0_H, chanData[channel].jtMode == 0);
    drawLabel(JTM1_LX, JTM1_LY, "JT4G", TFT_BLUE,0);
    drawOnOff(JTM1_X, JTM1_Y, JTM1_W, JTM1_H, chanData[channel].jtMode == 1);
    if(!activeChip->jt4Only)
      {
      drawLabel(JTM2_LX, JTM2_LY, "Q65", TFT_BLUE,0);
      drawOnOff(JTM2_X, JTM2_Y, JTM2_W, JTM2_H, chanData[channel].jtMode >= 2);
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

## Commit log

2025-03-18 Improve save button
2025-03-19 Add CW Enable Button
2025-04-21 Add Touchscreen recalibration
    Force touchscreen recalibration if the screen is touched during power on.
2025-12-16 Add Battery Display
2026-07-24 Add PICO DIsplay PCB
    [PICO_Display.kicad_pcb, Pico_Display.kicad_sch]
2026-08-04 Add BOM
    [PICO_Display_BOM.csv]
2026-08-12 Add Battery Calibration
